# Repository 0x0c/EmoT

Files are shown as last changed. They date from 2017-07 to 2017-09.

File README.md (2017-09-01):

# EmoT

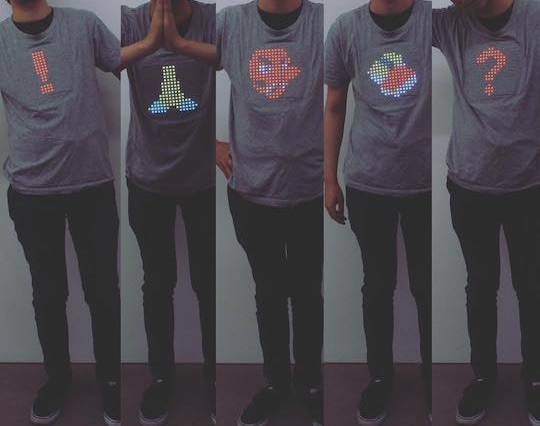
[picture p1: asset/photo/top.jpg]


## Requirements

- [Arduino Due](https://store.arduino.cc/usa/arduino-due)
- [Anker Astro E7](https://jp.anker.com/products/A1210012)
- [Flexible 16x16 NeoPixel RGB LED Matrix](https://www.adafruit.com/product/2547)
- [曲げセンサ](https://www.sparkfun.com/products/8606) * 5個
- [Konashi](http://konashi.ux-xu.com)
- [加圧インナー](https://www.amazon.co.jp/InField-加圧インナー-補正下着-ダイエット-コンプレッションウェア/dp/B01H8E9TIO)
- [Tシャツ](https://www.amazon.co.jp/dp/B0063XSIEI/ref=pe_2107282_266464282_TE_3p_dp_1)（適当なシャツでOK）
- [ウエストポーチ](https://www.amazon.co.jp/EYST-ランナーウェストポーチ-厚さわずか1mm-海外＆国内旅行用セキュリティポーチ-5-5インチまでのスマホ収納可能/dp/B01JOB6MMA)

## Usage

### Wear

0. 加圧インナーをTシャツの中に着る。
0. Arduino Dueをポーチに入れる。
0. バッテリーとArduino Due, LEDマトリクスを接続する。

### Pose Calibration

0. `Arduino/EmoT_Calibration/EmoT_Calibration.ino`をArduino Dueに書き込む。
0. センサスーツとArduino Dueを接続する。
0. Arduinoのコンソールでラベルを入力しEnterを押す。押したタイミングからセンサ値の読み出しを繰り返すので、認識させたいポーズを取る。
0. ポーズデータが集まったらWekaを使い分類する。`Classify > More Option`から`Output source code`にチェックを入れる。テキストフィールドには`PoseDetector`と入力する。
0. Wekaが出力したJavaのコードを`Arduino/EmoT_Calibration`に`PoseDetector.java`という名前で保存する。
0. コマンドラインから`python replace.py`を実行する。
0. 出力された`PoseDetector.h`を`Arduino/EmoT_firmware`以下にコピーする。

### App

0. Konashiに接続することでiPhone/iPod touchから操作可能。
0. Manual Modeをタッチすることで操作可能状態になる。
0. もう一度タッチするとポーズ推定モードに移行する。
0. Demo Modeは一度タッチすると5秒おきに表示が変わる。途中で中断できないので、すぐやめたいときはArduino Dueを再起動する（リセットボタンを押す）。

## Sensor Suit

### 曲げセンサの位置
- 肩 * 2個
- 胸 * 2個
- 背中 * 1個

詳細は`asset/sensor_suit`以下の写真参考。

## その他
- `EmoT_LED_Test`と`EmoT_SensorTest`はLEDマトリクスやセンサの動作確認用。
- `cad`以下のstlファイルはセンサスーツに曲げセンサを固定するためのパーツ。
- `tool/weka/weka_cli_command.sh`はWekaのSimple CLIからコードを生成するときのコマンド。
- `tool/emoji2code`は絵文字画像をC言語の配列に変換する。`./gen.sh <filename>`で`filename.txt`というテキストファイルが生成される。pngファイルのみ対応。ImageMagickが必要。

## Caption
私たちは言葉や身体の動きを使って人とコミュニケーションする。 言葉を声に出しながら、表情を変え、ジェスチャーを交えることで、自分の思いを相手に伝える。絵文字はこれらを代替してくれるツールだ。表情やジェスチャーが伝わらないメールやチャットでのコミュニケーションにおいて、テキストだけでは伝わらない思いを絵に込めて、相手に伝えることができる。 しかし、絵文字はコンピュータの世界でしか使うことができない。この作品は、身体の動きに合わせて絵文字を洋服に転写することで絵文字を実空間に持ち込むみコミュニケーションを拡張するとともに、心の「すきま」から漏れる伝えきれない思いを表現する。（東京大学制作展Extra SUKIMANIAC）

## Exhibition
- 東京大学制作展Extra SUKIMANIAC, 7/7~7/10, 2017
- TEDxUTokyo, 7/16, 2017
- Maker Faire Tokyo, 8/5~8/6, 2017

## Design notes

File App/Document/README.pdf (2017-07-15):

# Konashi Instpector

取扱説明書

# Version 1.0.0

2015/04/18

# Introduction

はじめに

Konashi InspectorはKonashiの動作を確認するためのiOS用アプリケーショ ンです。GitHubにてオープンソースプロジェクトとして運用されています。 (https://github.com/YUKAI/KonashiInspector)

Konashiを使った作品の制作・デバッグにご活用ください。なお、Konashiに 関する製品情報はこちらのホームページをご参照ください。 (http://konashi.ux-xu.com)

# Requirement

必要なもの

Konashi InspectorはiOS7.0以上の端末動作します。また、Bluetoothの機 能を使うには実機である必要があるため、本アプリを実機に転送できる環境 が必要になります。

# Getting Started with Konashi Inspector

Konashi Inspectorを使いはじめる

Konashi InspectorはGitHubからクローン可能です。CocoaPodsを用いて 依存モジュールを管理しておりますので、クローン後pod instlallコマンドの 実行が必要です。以下の順番にコマンドを実行してください。なお、pod installコマンドは時間がかかることがあります。

最後のコマンドを実行すると自動でXcodeが立ち上がります。実機転送する デバイスを選択し、証明書やプロビジョニングファイルの設定を確認のうえ 転送してください。

git clone git@github.com:YUKAI/KonashiInspector.git cd KonashiInspector
pod install
open KonashiInspector.xcworkspace

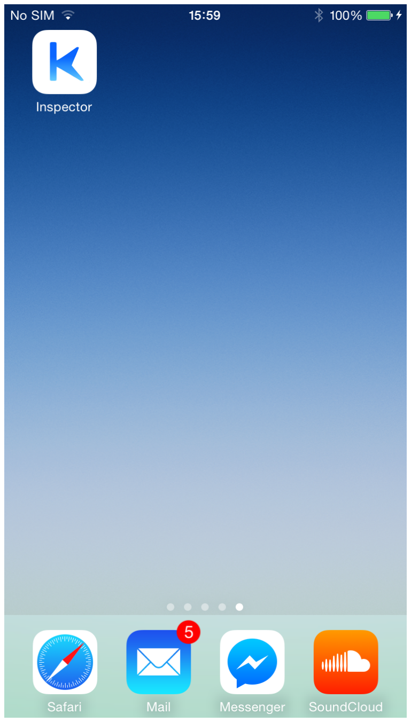
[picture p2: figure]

# Functions

機能

Konashi Inspectorには次の機能が搭載されています。

Konashiの名前の確認

Konashiのファームウェアバージョン(Revision)の確認

RSSIの確認

バッテリ残量の確認

OTAによるファームウェアアップデート

PIOの値の取得・変更

AIOの値の取得・変更

PWMの設定

UART・I2Cによる通信

# How to use

アプリケーションの使い方

## Konashiの状態の確認

Konashi Inspectorでは接続しているKonashiの状態を確認することができ ます。

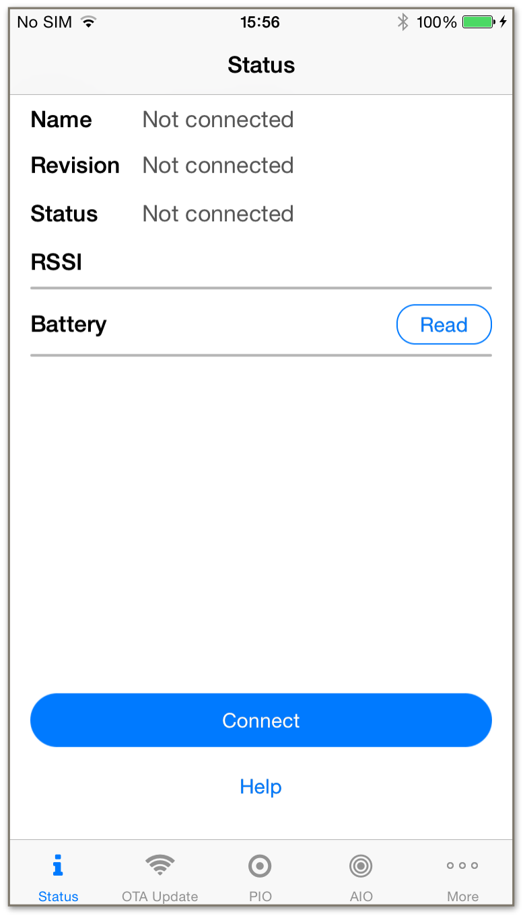
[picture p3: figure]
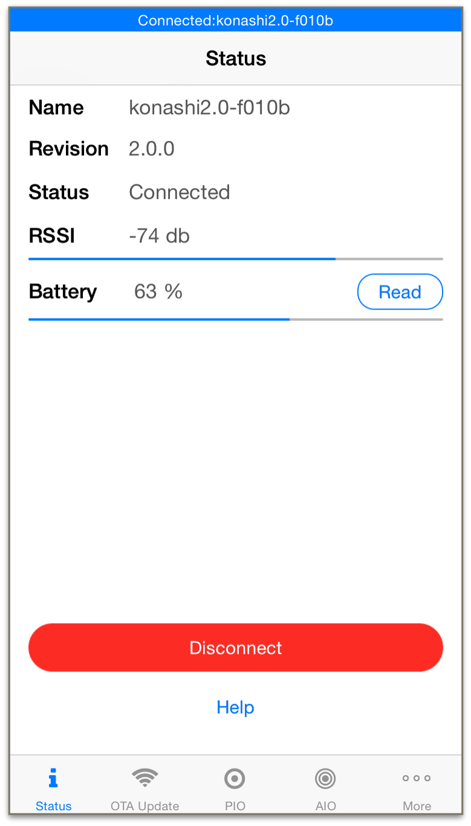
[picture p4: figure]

下タブに含まれている”Status”画面から確認することが可能です。この画面

にはName(Konashiの名前)、Revision(ファームウェアのバージョン)、 Status(接続状態)、RSSI(電波強度)、Battery(バッテリ残量)を確認すること ができます。Konashiが接続されるとステータスバー(画面上の時計やバッテ リ残量が表示されている場所)に接続中のKonashiの名前が表示されます。 “Connect”ボタンを押すことにより接続可能なKonashiを探して表示します。 接続したいKonashiの名前をタップすることにより接続することが可能です。 バッテリ残量はREADボタンを押すたびに確認できます。接続中のKonashiを

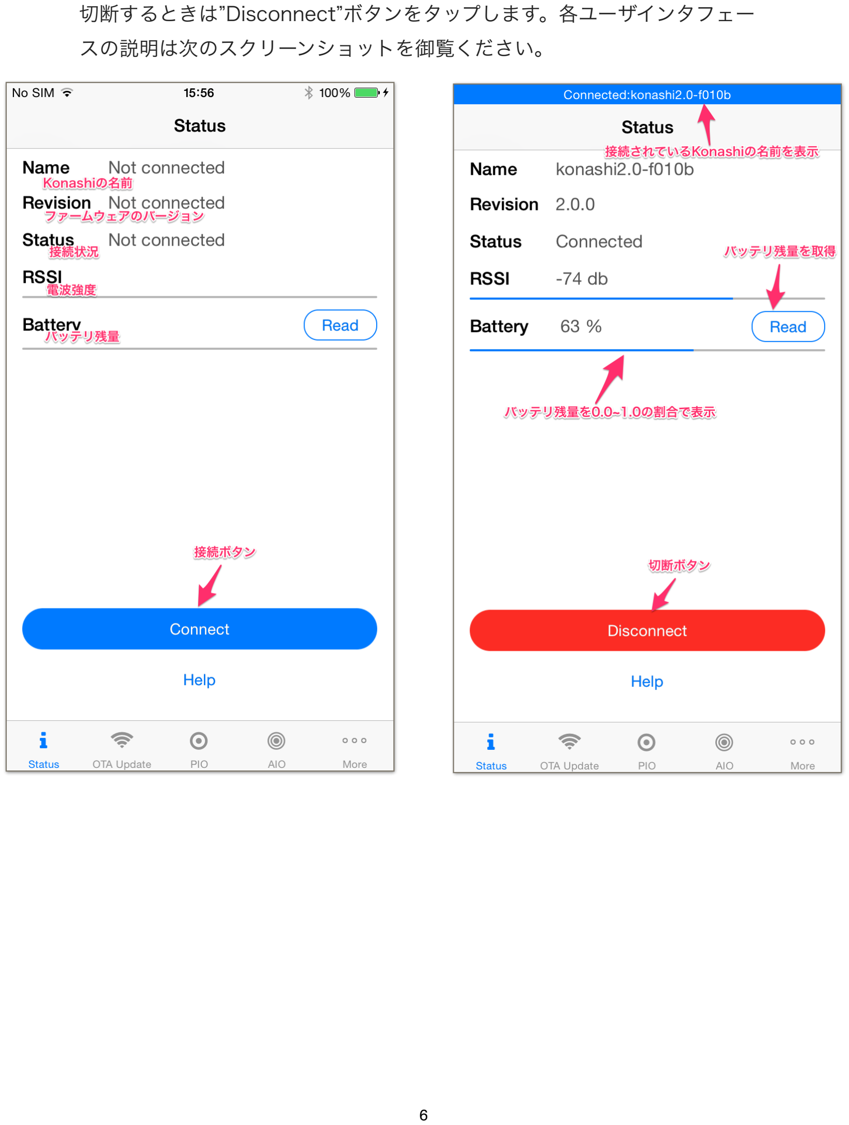
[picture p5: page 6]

切断するときは”Disconnect”ボタンをタップします。各ユーザインタフェー スの説明は次のスクリーンショットを御覧ください。

## OTAアップデート

koshian及びkonashi2はOTA(Over-The-Air)によるファームウェアアップ デートに対応しています。ファームウェアを書き換えることにより、不具合 修正や新機能を使えるようになります。OTA機能は、下タブに含まれる”OTA

Update”画面から利用できます。

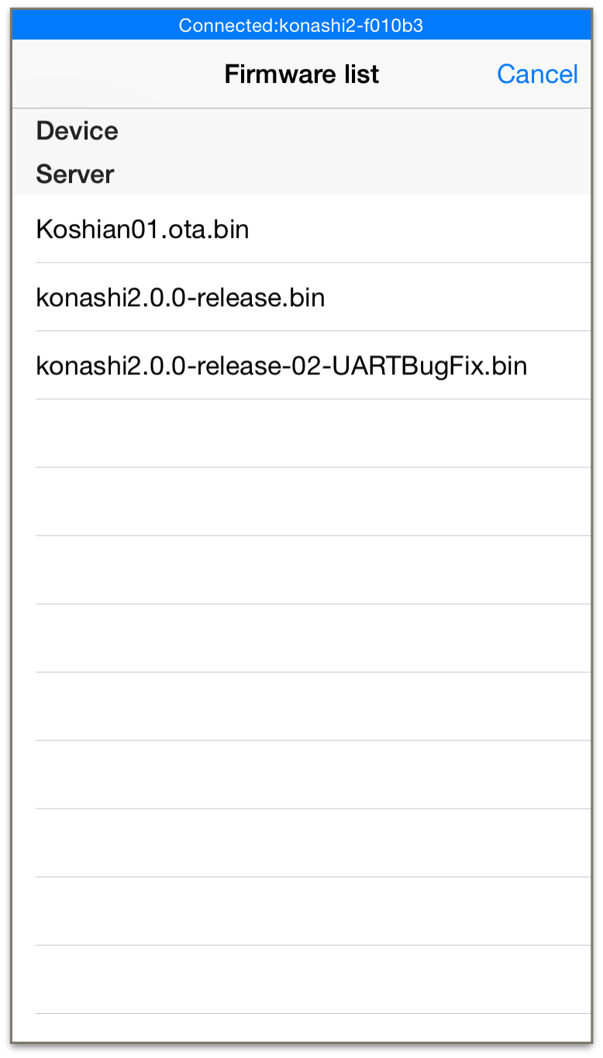
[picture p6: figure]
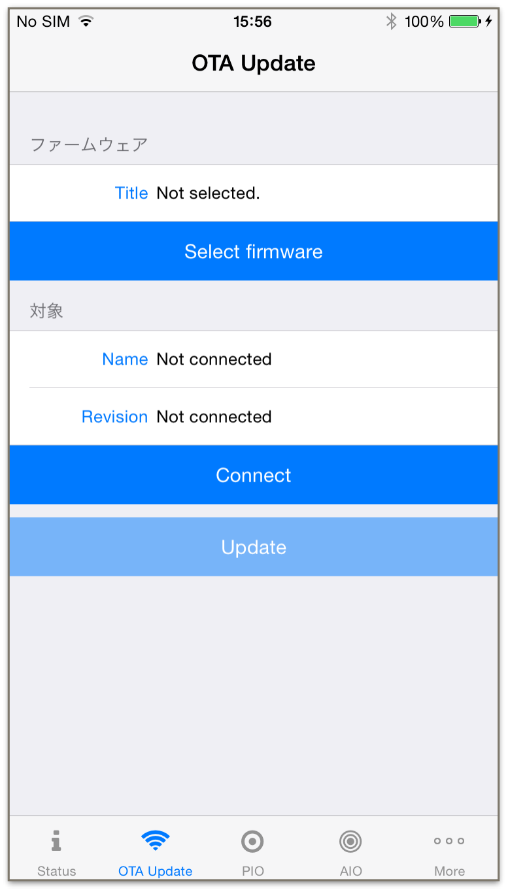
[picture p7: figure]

“Select firmware”ボタンをタップすると書き込むファームウェアを選択する 画面を表示します。”Device”セクションにはアプリに含まれているファーム ウェアが、”Server”セクションにはユカイ工学が提供しているファームウェ アが表示されます。アプリ内にファームウェアを含めるには、Xcodeプロジェ クトにファームウェアファイルをコピーし、実機に転送してください。 ファームウェア・アップデートするKonashiを設定し、“Update”ボタンを押 すことによりOTAアップデートを実行することができます。OTAアップデー ト時は画面に表示されるアラートにしたがってください。

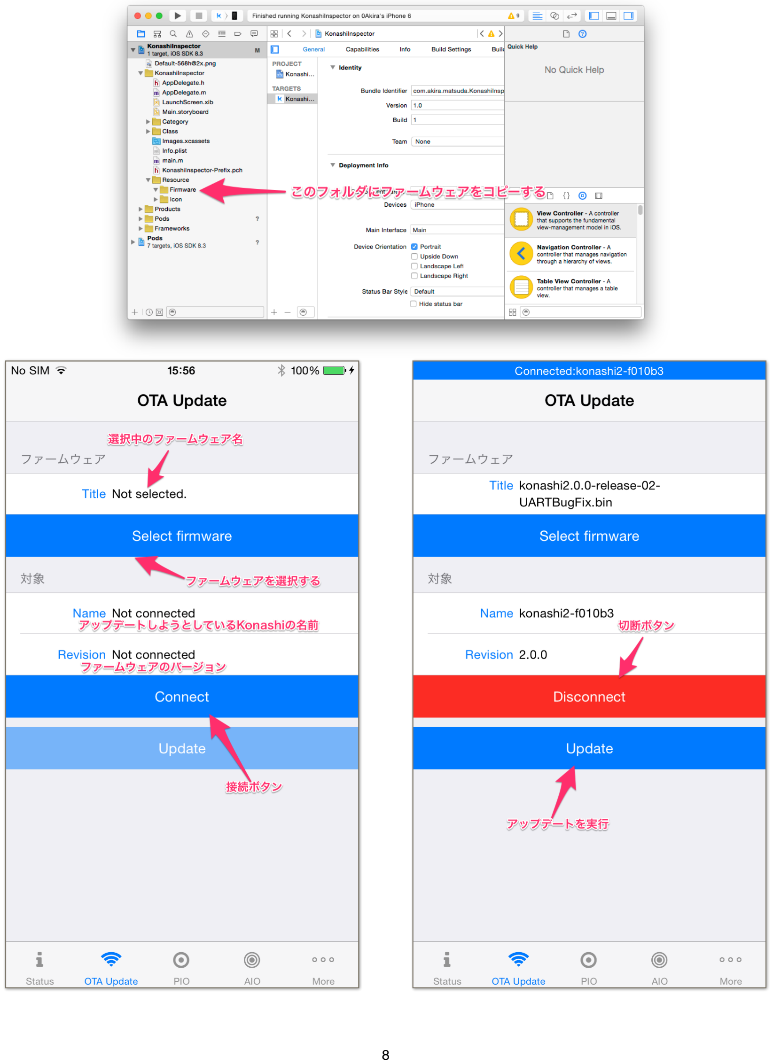
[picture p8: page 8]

## PIOの値の取得・変更

下タブの”PIO”画面からKonashiのPIOの状態を確認することができます。

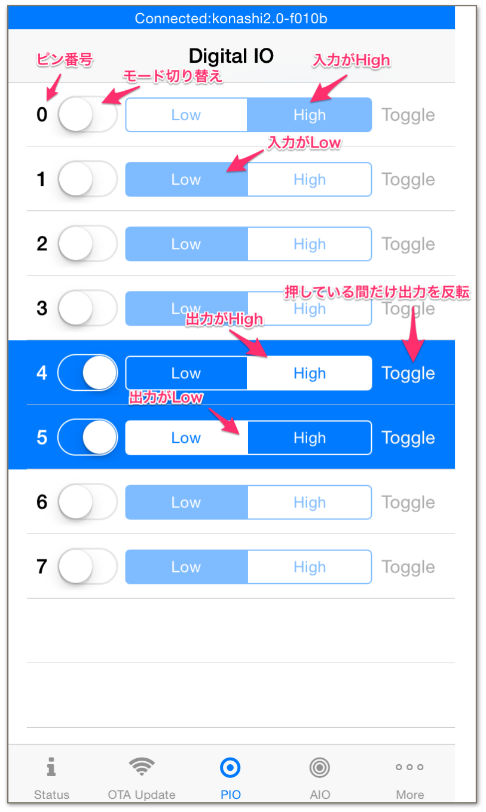
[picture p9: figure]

各行の左に表示されている数字はピン番号と対応しています。各ピンのモー ドは入力モードですが、デフォルトでは隣のスイッチをONにすることでPIO のモードを出力モードに切り替えることができます。出力モードに設定した ピンの行は背景色が青色になります。出力モードでは、”Toggle”ボタンを タップしている間だけ設定している値を反転させる事ができます。

## AIOの値の取得・変更

下タブの”AIO”画面からKonashiのAIOの状態を確認することができます。

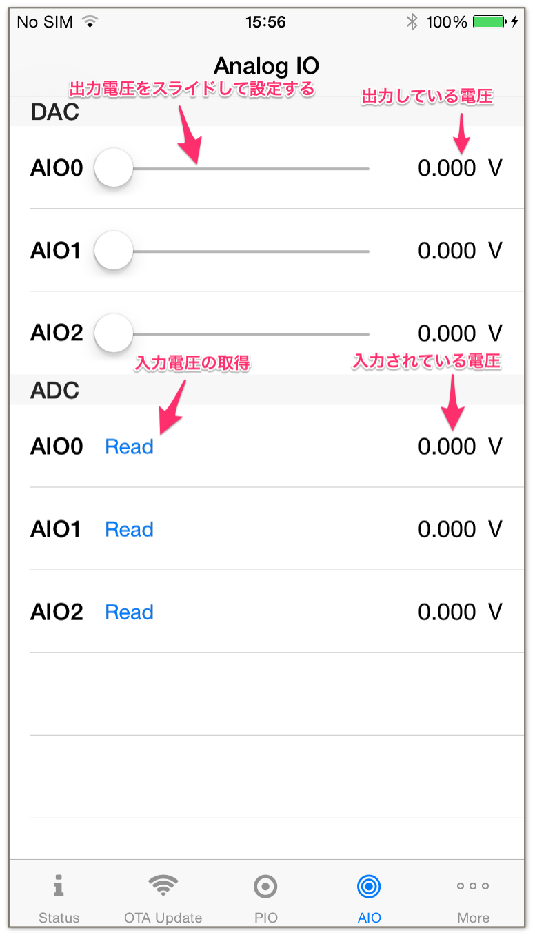
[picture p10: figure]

DACセクションのスライダを動かして出力電圧を設定できます。出力してい る電圧は各行の左に表示されます。ADCセクションの”Read”ボタンを押して 各ピンに入力されている電圧を取得できます。取得した電圧は各行の左に表 示されます。

## PWMの設定

下タブの”More”画面からKonashi Inspectorに搭載されている更なる機能

を利用できます。

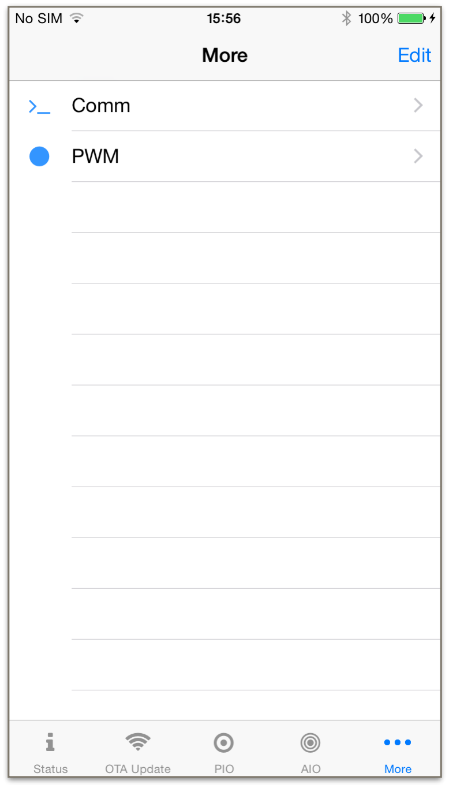
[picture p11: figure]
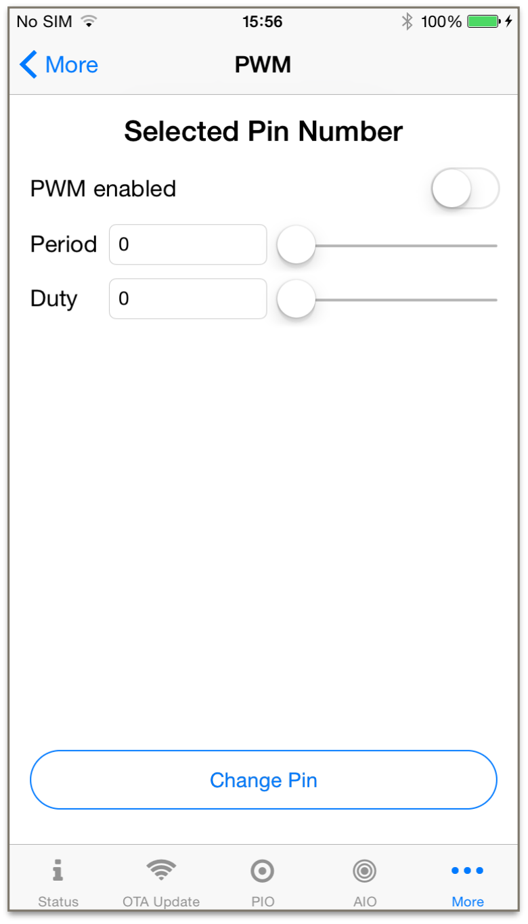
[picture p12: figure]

“PWM enabled”の隣にあるボタンをONにすることで、PWMモードを有効 にすることができます。”Period”と”Duty”はテキストフォームまたはスライダ で値を変更することができます。”Change Pin”ボタンをタップすることでピ ンを変更することができます。ピンを変更してもPWMの設定は保持されます。 （アプリ起動中のみ）

## UART・I2Cを利用する

“More”画面から表示できる”Comm”画面からUART・I2Cを用いて通信す ることができます。

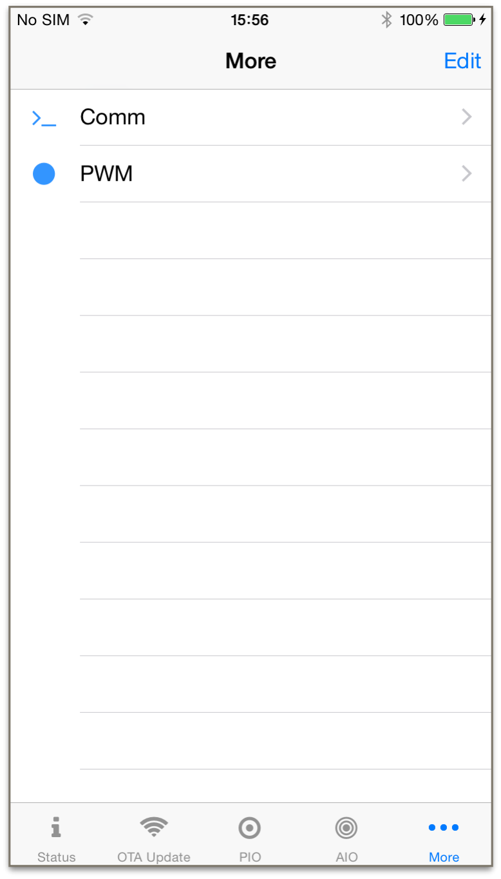
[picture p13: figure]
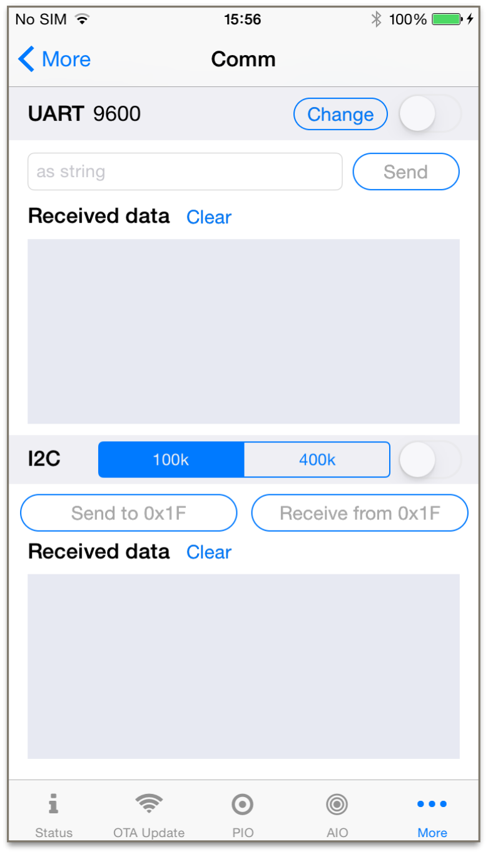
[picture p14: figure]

スイッチをONにすることでUART及びI2Cの機能を利用することができます。 ボーレートや速度を変更するためには、一度それぞれの機能をOFFにする必 要があります。UARTではテキストフォームに文字列を入力することで、 ASCIIデータを送信することができます。I2Cは0x1F番地にテストデータの書 き込みや読み出しができます。

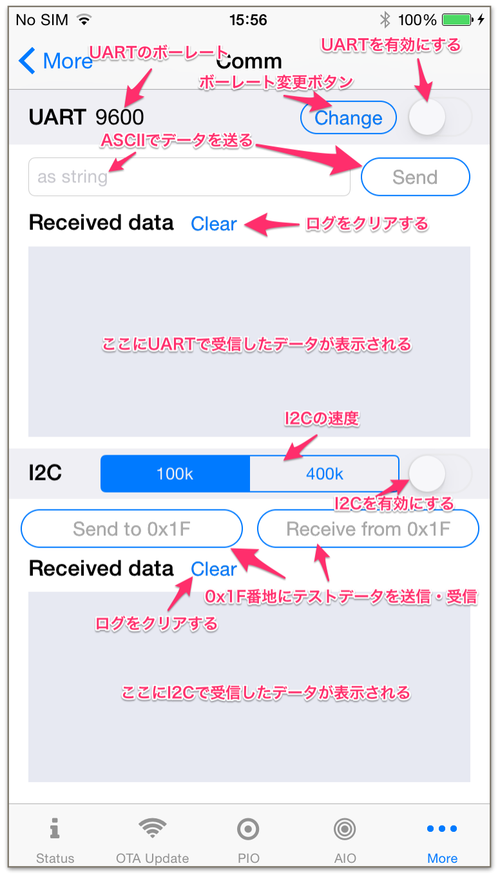
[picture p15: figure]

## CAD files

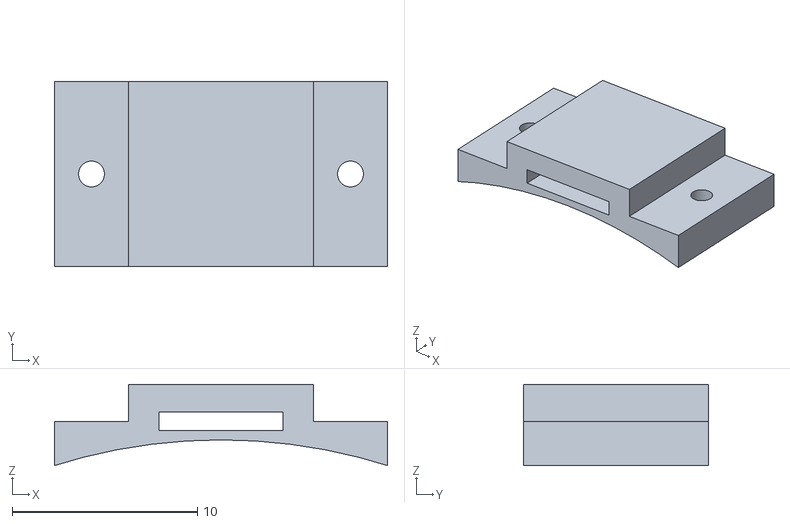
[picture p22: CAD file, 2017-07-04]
cad/sensor_holder1/sensor_holder1.stl
18.0 x 10.0 x 4.39

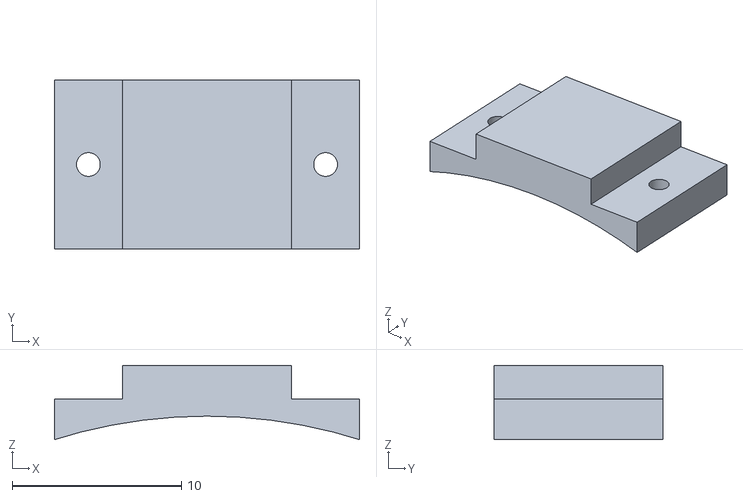
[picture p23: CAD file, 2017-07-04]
cad/sensor_holder2/sensor_holder2.stl
18.0 x 10.0 x 4.39

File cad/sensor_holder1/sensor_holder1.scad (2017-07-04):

difference() {
    translate([-9, -5, 0])
    cube([18, 10, 5]);
    
    translate([5, -5, 3])
    cube([5, 10, 3]);
    
    translate([-10, -5, 3])
    cube([5, 10, 3]);
    
    translate([7, 0, 0])
    cylinder(h=10, r1=1, r2=0, $fn=100);
    
    translate([-7, 0, 0])
    cylinder(h=10,r1=1, r2=0, $fn=100);
    
    translate([0, 0, -28])
    rotate([90,0,0])
    cylinder(h=11, r1=30, r2=30, center=true, $fn=100);
    
    translate([0, 0, 3])
    cube([6.7, 10, 1], center = true);
}

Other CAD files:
cad/sensor_holder2/sensor_holder2.scad

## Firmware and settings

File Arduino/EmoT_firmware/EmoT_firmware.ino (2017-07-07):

#include <stdio.h>
#include "Emoticon.h"
#include "EmoT.h"

using namespace m2d;

class AppState
{
	private:
	bool manualMode = false;
	bool autoMode = false;
	int counter = 0;
	int weight[6] = {0};

	void dispatch() {
		if (this->dispatchHandler){
			int max_index = PoseDetector::Pose::question;
			int max = this->weight[PoseDetector::Pose::question];
			if(max < this->weight[PoseDetector::Pose::arm]){
				max = this->weight[PoseDetector::Pose::arm];
				max_index = PoseDetector::Pose::arm;
			}
			if(max < this->weight[PoseDetector::Pose::vsign]){
				max = this->weight[PoseDetector::Pose::vsign];
				max_index = PoseDetector::Pose::vsign;
			}
			if(max < this->weight[PoseDetector::Pose::beer]){
				max = this->weight[PoseDetector::Pose::beer];
				max_index = PoseDetector::Pose::beer;
			}
			if(max < this->weight[PoseDetector::Pose::sushi]){
				max = this->weight[PoseDetector::Pose::sushi];
				max_index = PoseDetector::Pose::sushi;
			}
			if(max < this->weight[PoseDetector::Pose::standing]){
				max = this->weight[PoseDetector::Pose::standing];
				max_index = PoseDetector::Pose::standing;
			}
			this->dispatchHandler(max_index);
		}
	}

	void flushWeight() {
		for(int i = 0; i < 6; i++){
			this->weight[i] = 0;
		}
	}

	public:
	int dispatchInterval;
	void (*dispatchHandler)(int);
	void (*manualModeHandler)(String);
	void (*autoModeHandler)();

	AppState() {
		this->dispatchInterval = 20;
		this->dispatchHandler = nullptr;
		this->manualModeHandler = nullptr;
		this->autoModeHandler = nullptr;
	}

	bool isManualMode() {
		return this->manualMode;
	}

	bool isAutoMode() {
		return this->autoMode;
	}

	bool toggleManualMode() {
		this->manualMode = !this->manualMode;
		return this->isManualMode();
	}

	void setManualMode(bool enabled) {
		this->manualMode = enabled;
	}

	bool toggleAutoMode() {
		this->autoMode = !this->autoMode;
		return this->isAutoMode();
	}


	void setAutoMode(bool enabled) {
		this->autoMode = enabled;
	}

	void update(int pose, String comm) {
		if (this->isAutoMode()) {
			if(this->autoModeHandler) {
				Serial3.println("auto");
				this->autoModeHandler();
			}
		}
		else if (this->isManualMode()) {
			if (this->manualModeHandler) {
				Serial3.println("manual");
				this->manualModeHandler(comm);
			}
		}
		else {
			switch (pose) {
				case PoseDetector::Pose::question: // 左手を腰に手を当て、右手を頭に当てる
					this->weight[PoseDetector::Pose::question]++;
					break;
				case PoseDetector::Pose::arm: // 右腕の力こぶをふくらませるように腕を曲げる
					this->weight[PoseDetector::Pose::arm]++;
					break;
				case PoseDetector::Pose::vsign: // 左手を前に突き出す
					this->weight[PoseDetector::Pose::vsign]++;
					break;
				case PoseDetector::Pose::beer: // 前のめりになり、左向きに走るようなポーズ
					this->weight[PoseDetector::Pose::beer]++;
					break;
				case PoseDetector::Pose::sushi:
					this->weight[PoseDetector::Pose::sushi]++;
					break;
				case PoseDetector::Pose::standing:
					this->weight[PoseDetector::Pose::standing]++;
					break;
				default:
					break;
			}

			this->counter++;
			if (this->counter == 40) {
				this->dispatch();
				this->flushWeight();
				this->counter = 0;
			}
		}
	}
};

EmoT tee;
AppState state;
void setup()
{
	tee.clear();
	Serial.begin(9600);
	Serial3.begin(9600);
	state.dispatchHandler = drawImage;
	state.manualModeHandler = dispatchCommand;
	state.autoModeHandler = playDemo;
}

void loop()
{
	tee.updateValues();
	int s_l = tee.getSensorValue(EmoT::SensorPosition::SholderLeft);
	int sj_l = tee.getSensorValue(EmoT::SensorPosition::SholderJointLeft);
	int s_r = tee.getSensorValue(EmoT::SensorPosition::SholderRight);
	int sj_r = tee.getSensorValue(EmoT::SensorPosition::SholderJointRight);
	int bk = tee.getSensorValue(EmoT::SensorPosition::Back);
	String comm = "";
	if (Serial3.available()) {
		comm = Serial3.readStringUntil('.');
		Serial.println(comm);
		if (comm == "~") {
			Serial.println("manual mode true");
			state.setManualMode(true);
		}
		else if (comm == "!") {
			Serial.println("manual mode false");
			state.setManualMode(false);
		}
		else if (comm == "=") {
			Serial.println("auto mode true");
			state.setAutoMode(true);
		}
		else if (comm == "+") {
			Serial.println("auto mode false");
			state.setAutoMode(false);
		}
	}

	int values[5] = {s_l, sj_l, s_r, sj_r, bk};
	state.update(PoseDetector::classify(values), comm);
}

void drawImage(int pose)
{
	switch (pose) {
		case PoseDetector::Pose::question:
			tee.draw(Emoticon::question);
			Serial.println("question");
			break;
		case PoseDetector::Pose::arm:
			tee.draw(Emoticon::arm);
			Serial.println("arm");
			break;
		case PoseDetector::Pose::vsign:
			tee.draw(Emoticon::vsign);
			Serial.println("vsign");
			break;
		case PoseDetector::Pose::beer:
			tee.draw(Emoticon::beer);
			Serial.println("beer");
			break;
		case PoseDetector::Pose::sushi:
			tee.draw(Emoticon::sushi);
			Serial.println("sushi");
			break;
		case PoseDetector::Pose::standing:
			tee.clear();
			Serial.println("standing");
			break;
		default:
			break;
	}
}

void dispatchCommand(String comm)
{
	if (comm == "1") {
		tee.draw(Emoticon::question);
	}
	else if (comm == "2") {
		tee.draw(Emoticon::arm);
	}
	else if (comm == "3") {
		tee.draw(Emoticon::vsign);
	}
	else if (comm == "4") {
		tee.draw(Emoticon::beer);
	}
	else if (comm == "5") {
		tee.draw(Emoticon::heart);
	}
	else if (comm == "6") {
		tee.draw(Emoticon::pray);
	}
	else if (comm == "7") {
		tee.draw(Emoticon::tengu);
	}
	else if (comm == "8") {
		tee.draw(Emoticon::sushi);
	}
	else if (comm == "9") {
		tee.draw(Emoticon::exclamation);
	}
	else if (comm == "a") {
		tee.draw(Emoticon::sorry);
	}
	else if (comm == "b") {
		tee.draw(Emoticon::ban);
	}
	else if (comm == "c") {
		tee.draw(Emoticon::success);
	}
	else if (comm == "d") {
		tee.draw(Emoticon::fire);
	}
	else if (comm == "e") {
		tee.draw(Emoticon::notgood);
	}
	else if (comm == "-") {
		tee.clear();
	}
}

void playDemo()
{
	tee.draw(Emoticon::question);
	delay(5000);

	tee.draw(Emoticon::arm);
	delay(5000);

	tee.draw(Emoticon::vsign);
	delay(5000);

	tee.draw(Emoticon::beer);
	delay(5000);

	tee.draw(Emoticon::heart);
	delay(5000);

	tee.draw(Emoticon::pray);
	delay(5000);

	tee.draw(Emoticon::tengu);
	delay(5000);

	tee.draw(Emoticon::sushi);
	delay(5000);

	tee.draw(Emoticon::exclamation);
	delay(5000);

	tee.draw(Emoticon::sorry);
	delay(5000);

	tee.draw(Emoticon::ban);
	delay(5000);

	tee.draw(Emoticon::success);
	delay(5000);

	tee.draw(Emoticon::fire);
	delay(5000);
}

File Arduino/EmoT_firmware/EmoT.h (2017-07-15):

#include <Adafruit_NeoPixel.h>
#include "PoseDetector.h"

namespace m2d {
	#define kVoltage 3.3
	#define PIN 13
	#define N_LEDS 256

	class EmoT
	{
		private:
		Adafruit_NeoPixel strip;
		int sensorValues[5] = { 0 };
		public:
		enum SensorPosition {
			SholderLeft = 0,
			SholderJointLeft,
			SholderRight,
			SholderJointRight,
			Back
		};

		EmoT() {
			this->setup();
		}

		EmoT(int baudrate) {
			Serial.begin(baudrate);
			this->setup();
		}

		void setBrightness(int brightness) {
			this->strip.setBrightness(brightness);
		}

		void updateValues() {
			for(int i = 0; i < 5; i++){
			    this->sensorValues[i] = this->getCurrentSensorValue(i);
			}
		}

		int getSensorValue(int index) {
			return this->sensorValues[index];
		}

		int getCurrentSensorValue(int index) {
			int iValue = analogRead(index);
			double dV = iValue * kVoltage  / 1023;
			double dR = -1.0;

			if( 0.005 < (kVoltage  - dV) ) {
				dR = 10 * 1000 * dV / (5.0  - dV);
			}
			if( 0.0 > dR ) {
				return -1;
			}
			
			return dR;
		}

		void draw(unsigned char img[16][16][3], bool flip = false) {
			if (this->currentImageAddr != &(img[0][0][0])) {
				this->currentImageAddr = &(img[0][0][0]);
				if (flip) {
					for (int time = 0; time <= 32; time++) {
						for (int i = 16 * 16; i >= 0; i--) {
							int idx = i / 16;
							int row = i % 16;
							int pos = i;

							float ratio = time / 32.0;
							uint32_t c = this->strip.Color(img[row][idx][0] * ratio, img[row][idx][1] * ratio, img[row][idx][2] * ratio);
							if (row % 2) {
								pos = (row + 1) * 16 - idx - 1;
							}
							this->strip.setPixelColor(pos, c);
						}
						this->strip.show();
						delay(1);
					}
				}
			 	else {
			 		for (int time = 0; time <= 32; time++) {
						for (int i = 0; i < 16 * 16; i++) {
							int row = i / 16;
							int idx = i % 16;
							int pos = i;

							float ratio = time / 32.0;
							uint32_t c = this->strip.Color(img[row][idx][0] * ratio, img[row][idx][1] * ratio, img[row][idx][2] * ratio);
							if (row % 2) {
								pos = (row + 1) * 16 - idx - 1;
							}
							this->strip.setPixelColor(pos, c);
						}
						this->strip.show();
						delay(1);
					}
				}
			}
		}

		void clear() {
			this->currentImageAddr = nullptr;
			this->strip.clear();
			this->strip.show();
		}

		private:
		unsigned char *currentImageAddr = nullptr;
		void setup() {
			this->strip = Adafruit_NeoPixel(N_LEDS, PIN, NEO_GRB + NEO_KHZ800);
			this->strip.begin();
			this->strip.setBrightness(30);
		}
	};
}
